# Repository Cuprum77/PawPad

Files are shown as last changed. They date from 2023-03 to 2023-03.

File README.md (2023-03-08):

# PawPad
## PawPad programming header
This is a project that aims to spice up the world of boring test jigs and programming headers with a completely new, full stack system for adding programming headers to your boards.
<div>
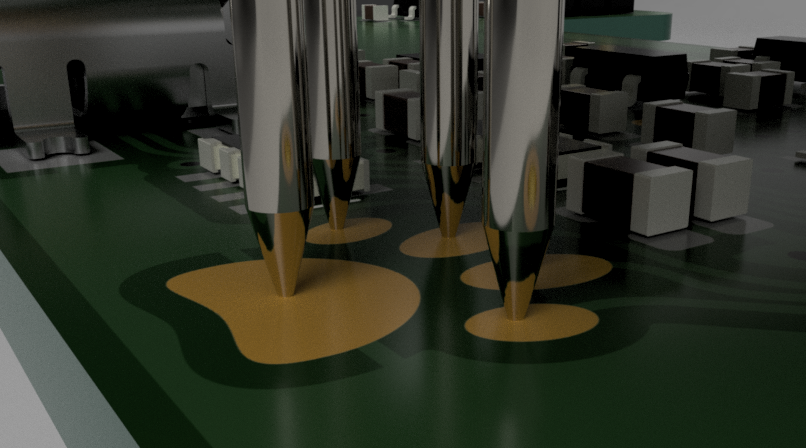
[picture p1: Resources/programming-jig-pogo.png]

</div>

## Why should I use this?

There are many benefits in the above shape compared to regular arrangements:
* No acid traps due to smooth curves
* No holes in the PCB means easier routing
* Big enough to solder wires to when needed, yet compact enough to be practical
* Large surface area makes it hard to peel the pads off and easier to hit with a jig
* Pretty
## Files
[PawPad](../main/PawPad) - contains the KiCAD footprint.

[Programming Jig](<../main/Programming Jig>) - contains a programming jig meant to be screwed onto a piece of 10x10 aluminium extrusion/makerbeam.
<div>
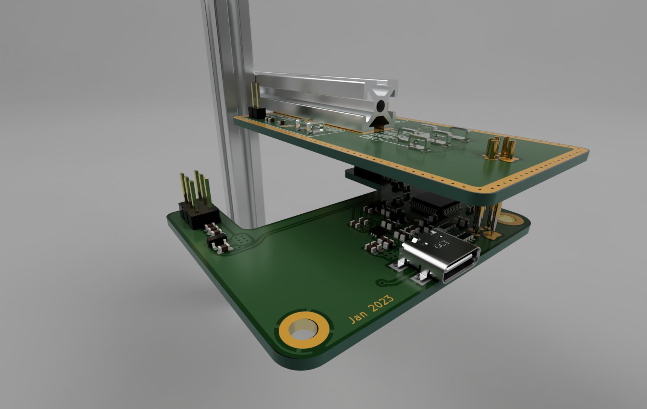
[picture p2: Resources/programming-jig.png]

</div>
NOTE: this jig is not complete! It has not yet been tested for actual programming and may not be ideal!

## Pinout
The pinout is standardized as outlined below:

Pin | SWD | JTAG | SPI / ICSP | UART | I2C
:---: | :---: | :---: | :---: | :---: | :---:
Bean (1) | SWO | TDO | MISO | RX | -
Bean (2) | SWDIO | TDI | MOSI | TX | SDA
Bean (3) | SWCLK | TCK | SCK | - | SCL
Bean (4) | NRST | TMS | RST | RST | RST
Big Bean (5) | GND | GND | GND | GND | GND

<div>
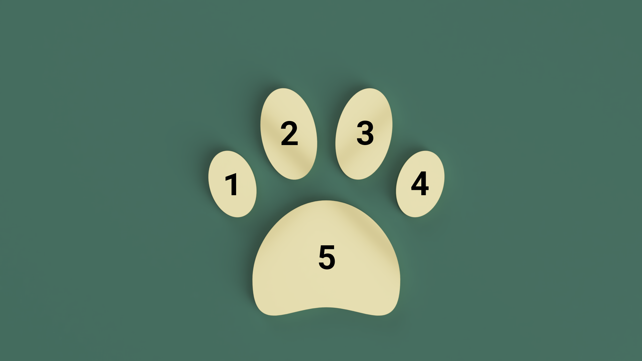
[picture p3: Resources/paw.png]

</div>

## Showcase
Did you add this to your PCBs? Let us know by opening an [Issue](https://github.com/Cuprum77/PawPad/issues/new)!

Example of the [Programming Jig](<../main/Programming Jig>) in action on a test PCB:
<div>
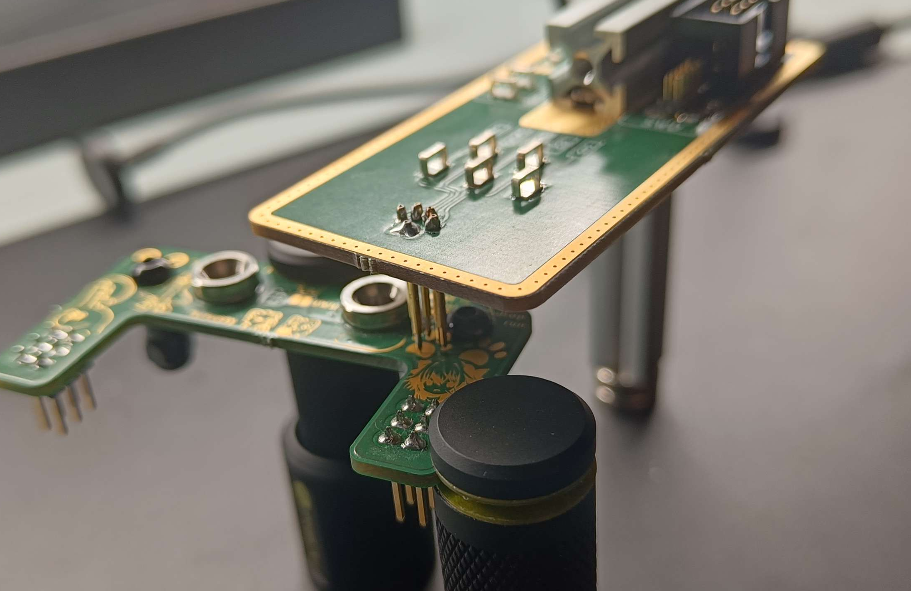
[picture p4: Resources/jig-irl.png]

</div>

## Future plans
* Alternative designs with different numbers of pins
* Unified pinout standard
* OSHW certification
* Debugger design

### Acknowlegments
This has been inspired by the [original maker of the footprint](https://github.com/the6p4c/pawpad), go check them out.

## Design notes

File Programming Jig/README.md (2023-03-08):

# PawPad Programming Jig
This is an experimental programming jig for PawPad. It still requires real world testing, but continuity tests have proven the design to be sound.

## Use case
This jig is meant to fan out the PawPad connector to the common SWD and ICSP connectors. 
Please do not try to connect them together or plug in other programmers than what you intend to use, as there is no protection circuitry on this!

## How to assemble
Soldering the jig is difficult, it is recommended that you order or get more than a single PCB made. That way you can screw them together and use the holes to keep the pogo pins straight. 

However, due to the size, it should be noted that they might be hard to solder by hand, and might require some fiddling get it to work.

## Future plans
* Add a 3D printable jig to hold the pogo pins in place
* Create a cheaper mounting solution

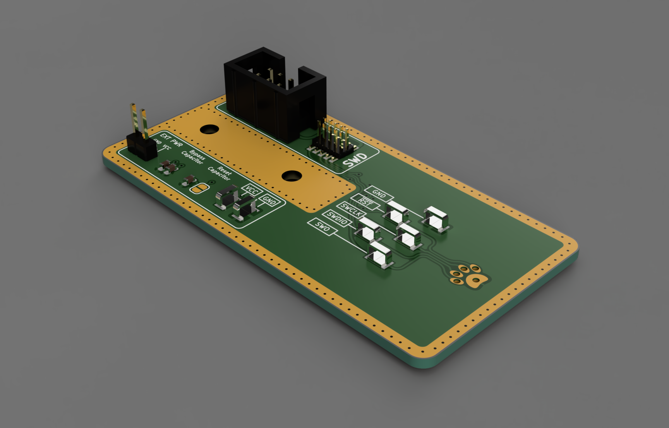
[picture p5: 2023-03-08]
Resources/jig.png

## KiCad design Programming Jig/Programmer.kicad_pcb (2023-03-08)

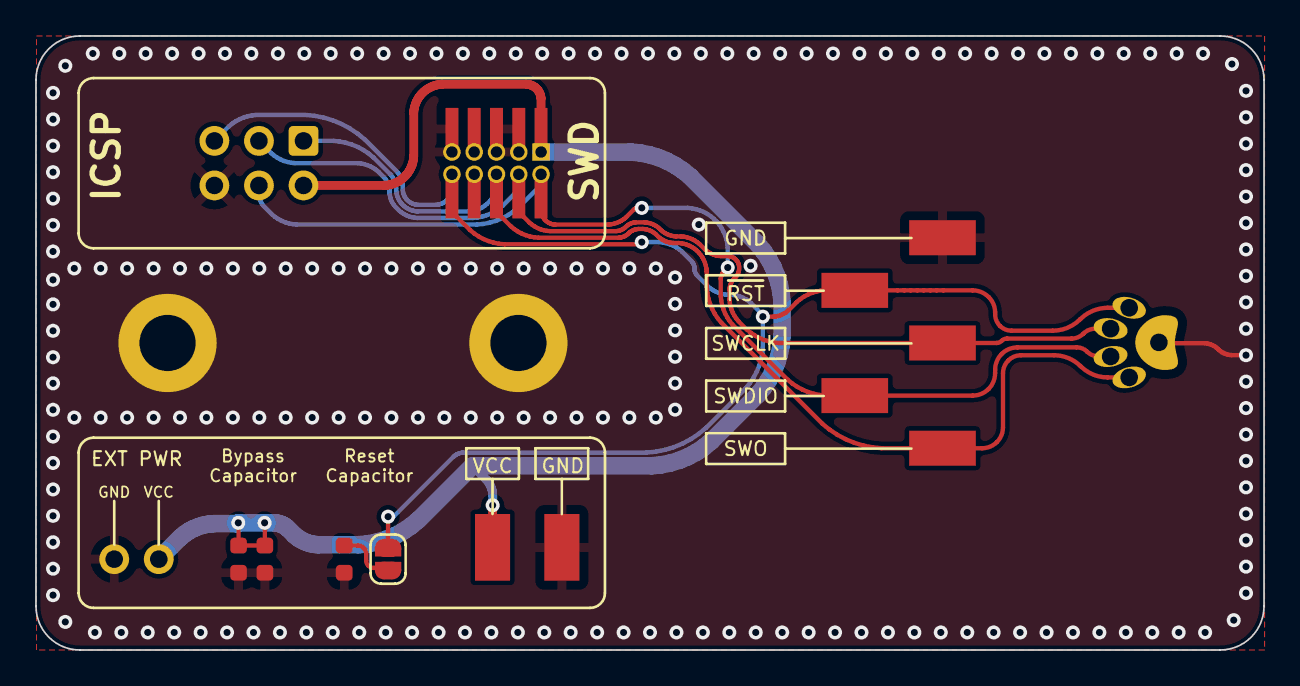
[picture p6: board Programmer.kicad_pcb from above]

Board: 2 copper layers, 70.0 x 35.0 mm, 18 parts (0 on the bottom side), 9 nets.

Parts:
C1, C2: 100n; C_0603_1608Metric
C3: 100p; C_0603_1608Metric
H1, H2: M3; MountingHole_3.2mm_M3_DIN965_Pad
J1: ICSP; IDC-Header_2x03_P2.54mm_Vertical
J2: PawPrint; pawpad_holeless
J3: PM20B05VBDN; PinHeader_2x05_P1.27mm_Vertical_SMD
J4: THT variant; PinHeader_2x05_P1.27mm_Vertical
J5: Power; PinSocket_1x02_P2.54mm_Vertical
JP1: RST Capacitor; SolderJumper-2_P1.3mm_Open_RoundedPad1.0x1.5mm
TP1, TP2, TP3, TP4, TP5: TestPoint; TestPoint_Keystone_5019_Minature_No_Silkscreen
TP6: 1; TestPoint_Keystone_5019_Minature_No_Silkscreen
TP7: 2; TestPoint_Keystone_5019_Minature_No_Silkscreen

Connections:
/NRST/RST: J1.5, J2.4, J3.10, J4.10, JP1.1 (A), TP5.1
/N/A_L: J3.7, J4.7
/N/A_R: J3.8, J4.8
/SWCLK/SCK: J1.3, J2.3, J3.4, J4.4, TP4.1
/SWDIO/MOSI: J1.4, J2.2, J3.2, J4.2, TP3.1
/SWO/MISO: J1.1, J2.1, J3.6, J4.6, TP1.1
GND: C1.2, C2.2, C3.2, H1.1, H2.1, J1.6, J2.5, J3.3, J3.5, J3.9, J4.3, J4.5, J4.9, J5.2, TP2.1, TP7.1
unnamed: C1.1, JP1.2 (B)
VCC: C2.1, C3.1, J1.2, J3.1, J4.1, J5.1, TP6.1
